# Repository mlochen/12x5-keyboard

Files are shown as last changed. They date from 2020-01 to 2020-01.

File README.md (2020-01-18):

# 12x5 keyboard

CAD file and keymap for an 12x5 keyboard with [qmk firmware](https://qmk.fm/).

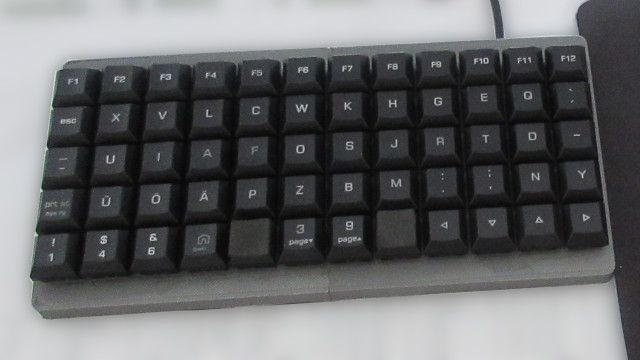
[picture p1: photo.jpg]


This is a hand wired keyboard. It uses the Cherry MX keyswitches and a Teensy 2.0 for the controller board.
The physical layout is a slightly modified version of the [Neo2 layout](https://neo-layout.org/), but the
keyboard can be used with the computer set to the german keyboard layout because the controller converts
the key presses to match the keycodes generated by a standard keyboard.
That makes it possible to use a Neo2 layout on computers that do not support it.

## How to build the firmware
* download the qmk firmware
* copy the "12x5" folder in the keyboards folder
* follow the instructions [here](https://docs.qmk.fm/#/newbs_building_firmware?id=build-your-firmware)

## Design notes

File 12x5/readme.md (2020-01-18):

# 12x5

12x5

A short description of the keyboard/project

Keyboard Maintainer: [Marco Lochen](https://github.com/mlochen)  
Hardware Supported: The PCBs, controllers supported  
Hardware Availability: links to where you can find this hardware

Make example for this keyboard (after setting up your build environment):

    make 12x5:default

See the [build environment setup](https://docs.qmk.fm/#/getting_started_build_tools) and the [make instructions](https://docs.qmk.fm/#/getting_started_make_guide) for more information. Brand new to QMK? Start with our [Complete Newbs Guide](https://docs.qmk.fm/#/newbs).

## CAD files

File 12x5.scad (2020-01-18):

/*
 * Copyright (C) 2019 Marco Lochen
 *
 * This work is licensed under the Creative Commons Attribution 4.0
 * International License. To view a copy of this license, visit
 * http://creativecommons.org/licenses/by/4.0/ or send a letter to Creative
 * Commons, PO Box 1866, Mountain View, CA 94042, USA.
 */

kbx = 228;          // size in x direction
kby = 95;           // size in y direction
bx = 1.8;           // border in x direction
by = 10;            // border in y direction
bh = 9;             // border height
a = 6;              // tilt angle

module base_plate()
{
    difference()
    {
        cube([kbx + 2 * bx, (kby + 2 * by) / cos(a), 1.5]);
        for (x = [0:11])
        {
            for (y = [0:4])
            {
                translate([x * 19 + 9.5 + bx, y * 19 + 9.5 + by, 0]) cube([14, 14, 10], center = true);
            }
        }
    }
}

module bracing()
{
    for (x = [1:11])
    {
        translate([x * 19 + bx - 0.4, -50, 0]) cube([0.8, (kby + 2 * by) / cos(a) + 100, 4]);
    }
    for (y = [1:4])
    {
        translate([-50, y * 19 + by - 0.4, 0]) cube([kbx + 2 * bx + 100, 0.8, 4]);
    }
}

module key_plate()
{
    intersection()
    {
        union()
        {
            base_plate();
            bracing();
        }
        rotate([a, 0, 0]) translate([bx / 2, by / 2, -50]) cube([kbx + bx, kby + by, 100]);
    }
}

module base_border()
{
    difference()
    {
        hull()
        {
            translate([4, 4, 0]) cylinder(h = 100, r = 4, $fn = 16);
            translate([4, kby + 2 * by - 4, 0]) cylinder(h = 100, r = 4, $fn = 16);
            translate([kbx + 2 * bx - 4, 4, 0]) cylinder(h = 100, r = 4, $fn = 16);
            translate([kbx + 2 * bx - 4, kby + 2 * by - 4, 0]) cylinder(h = 100, r = 4, $fn = 16);
        }
        translate([bx, by, -1]) cube([kbx, kby, 102]);
    }
}

module border()
{
    module bolt_cutout(h = 12)
    {
        cylinder(h = kby, r = 1.7, $fn = 16);
        translate([0, 0, -1.5]) cylinder(h = 4, r1 = 4, r2 = 0, $fn = 16);
        translate([0, 2, 1.4 + 3]) cube([5.8, 12, 2.8], center = true);
    }
    
    module wire_cut()
    {
        wire_d = 4.6;
        translate([0, wire_d / 2]) circle(r = wire_d / 2, $fn = 16);
        square([wire_d, wire_d], center = true);
    }
    
    module wire_cutout()
    {
        rotate([90, 0, 0]) linear_extrude(10) wire_cut();
        translate([10, 0, 0]) rotate([0, 0, 45]) rotate_extrude(angle = 135, $fn = 32)
            translate([10, 0]) wire_cut();
        translate([20 / sqrt(2) + 10, 20 / sqrt(2), 0]) rotate([0, 0, 225])
            rotate_extrude(angle = 135, $fn = 32) translate([10, 0]) wire_cut();
    }
        
    difference()
    {
        union()
        {
            base_border();
            translate([50, kby + 2 * by, 0]) difference()
            {
                cylinder(h = 16, r1 = 15, r2 = 10, $fn = 32);
                translate([0, 45, 0]) cube([100, 100, 100], center = true);
            }
        }
        translate([bx + 9.5, by / 2, 0]) bolt_cutout(8);
        translate([bx + 9.5, by + kby + by / 2, 0]) rotate([0, 0, 180]) bolt_cutout();
        translate([bx + kbx / 2 - 9.5, by / 2, 0]) bolt_cutout(8);
        translate([bx + kbx / 2 - 9.5, by + kby + by / 2, 0]) rotate([0, 0, 180]) bolt_cutout();
        translate([bx + kbx / 2 + 9.5, by / 2, 0]) bolt_cutout(8);
        translate([bx + kbx / 2 + 9.5, by + kby + by / 2, 0]) rotate([0, 0, 180]) bolt_cutout();
        translate([bx + kbx - 9.5, by / 2, 0]) bolt_cutout(8);
        translate([bx + kbx - 9.5, by + kby + by / 2, 0]) rotate([0, 0, 180]) bolt_cutout();
        
        translate([40, kby + 2 * by, 0]) mirror([0, 1, 0]) wire_cutout();
        
        translate([24, 2, -1]) cube([30, 6, 6]);
        translate([kbx + 2 * bx - 24 - 30, 2, -1]) cube([30, 6, 6]);
    }
}

module complete()
{
    key_plate();
    
    intersection()
    {
        rotate([a, 0, 0]) translate([0, 0, bh]) mirror([0, 0, 1]) border();
        translate([0, 0, 500]) cube([1000, 1000, 1000], center = true);
    }
}

module half1()
{        
    intersection()
    {
        complete();
        translate([-500 + kbx / 2 + bx, 0, 0]) cube([1000, 1000, 1000], center = true);
    }
}

module half2()
{        
    intersection()
    {
        complete();
        translate([500 + kbx / 2 + bx, 0, 0]) cube([1000, 1000, 1000], center = true);
    }
}

complete();
// for smaller print beds the keyboard can be printed in two halfes and then glued together
//half1();
//half2();

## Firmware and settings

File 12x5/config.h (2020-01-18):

/*
Copyright 2019 Marco Lochen

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
You should have received a copy of the GNU General Public License
along with this program.  If not, see <http://www.gnu.org/licenses/>.
*/

#pragma once

#include "config_common.h"

/* USB Device descriptor parameter */
#define VENDOR_ID 0xFEED
#define PRODUCT_ID 0x0000
#define DEVICE_VER 0x0001
#define MANUFACTURER Marco Lochen
#define PRODUCT 12x5
#define DESCRIPTION A custom keyboard

/* key matrix size */
#define MATRIX_ROWS 5
#define MATRIX_COLS 12

/*
 * Keyboard Matrix Assignments
 *
 * Change this to how you wired your keyboard
 * COLS: AVR pins used for columns, left to right
 * ROWS: AVR pins used for rows, top to bottom
 * DIODE_DIRECTION: COL2ROW = COL = Anode (+), ROW = Cathode (-, marked on diode)
 *                  ROW2COL = ROW = Anode (+), COL = Cathode (-, marked on diode)
 *
 */
#define MATRIX_ROW_PINS \
    { D0, D1, D2, D3, C6 }
#define MATRIX_COL_PINS \
    { D4, D6, D7, B4, B5, B6, F7, F6, F5, F4, F1, F0 }
#define UNUSED_PINS

/* COL2ROW, ROW2COL*/
#define DIODE_DIRECTION COL2ROW

/*
 * Split Keyboard specific options, make sure you have 'SPLIT_KEYBOARD = yes' in your rules.mk, and define SOFT_SERIAL_PIN.
 */
#define SOFT_SERIAL_PIN D0  // or D1, D2, D3, E6

// #define BACKLIGHT_PIN B7
// #define BACKLIGHT_BREATHING
// #define BACKLIGHT_LEVELS 3

// #define RGB_DI_PIN E2
// #ifdef RGB_DI_PIN
//   #define RGBLED_NUM 16
//   #define RGBLIGHT_HUE_STEP 8
//   #define RGBLIGHT_SAT_STEP 8
//   #define RGBLIGHT_VAL_STEP 8
//   #define RGBLIGHT_LIMIT_VAL 255 /* The maximum brightness level */
//   #define RGBLIGHT_SLEEP  /* If defined, the RGB lighting will be switched off when the host goes to sleep */
// /*== all animations enable ==*/
//   #define RGBLIGHT_ANIMATIONS
// /*== or choose animations ==*/
//   #define RGBLIGHT_EFFECT_BREATHING
//   #define RGBLIGHT_EFFECT_RAINBOW_MOOD
//   #define RGBLIGHT_EFFECT_RAINBOW_SWIRL
//   #define RGBLIGHT_EFFECT_SNAKE
//   #define RGBLIGHT_EFFECT_KNIGHT
//   #define RGBLIGHT_EFFECT_CHRISTMAS
//   #define RGBLIGHT_EFFECT_STATIC_GRADIENT
//   #define RGBLIGHT_EFFECT_RGB_TEST
//   #define RGBLIGHT_EFFECT_ALTERNATING
// /*== customize breathing effect ==*/
//   /*==== (DEFAULT) use fixed table instead of exp() and sin() ====*/
//   #define RGBLIGHT_BREATHE_TABLE_SIZE 256      // 256(default) or 128 or 64
//   /*==== use exp() and sin() ====*/
//   #define RGBLIGHT_EFFECT_BREATHE_CENTER 1.85  // 1 to 2.7
//   #define RGBLIGHT_EFFECT_BREATHE_MAX    255   // 0 to 255
// #endif

/* Debounce reduces chatter (unintended double-presses) - set 0 if debouncing is not needed */
#define DEBOUNCE 5

/* define if matrix has ghost (lacks anti-ghosting diodes) */
//#define MATRIX_HAS_GHOST

/* Mechanical locking support. Use KC_LCAP, KC_LNUM or KC_LSCR instead in keymap */
#define LOCKING_SUPPORT_ENABLE
/* Locking resynchronize hack */
#define LOCKING_RESYNC_ENABLE

/* If defined, GRAVE_ESC will always act as ESC when CTRL is held.
 * This is userful for the Windows task manager shortcut (ctrl+shift+esc).
 */
// #define GRAVE_ESC_CTRL_OVERRIDE

/*
 * Force NKRO
 *
 * Force NKRO (nKey Rollover) to be enabled by default, regardless of the saved
 * state in the bootmagic EEPROM settings. (Note that NKRO must be enabled in the
 * makefile for this to work.)
 *
 * If forced on, NKRO can be disabled via magic key (default = LShift+RShift+N)
 * until the next keyboard reset.
 *
 * NKRO may prevent your keystrokes from being detected in the BIOS, but it is
 * fully operational during normal computer usage.
 *
 * For a less heavy-handed approach, enable NKRO via magic key (LShift+RShift+N)
 * or via bootmagic (hold SPACE+N while plugging in the keyboard). Once set by
 * bootmagic, NKRO mode will always be enabled until it is toggled again during a
 * power-up.
 *
 */
//#define FORCE_NKRO

/*
 * Magic Key Options
 *
 * Magic keys are hotkey commands that allow control over firmware functions of
 * the keyboard. They are best used in combination with the HID Listen program,
 * found here: https://www.pjrc.com/teensy/hid_listen.html
 *
 * The options below allow the magic key functionality to be changed. This is
 * useful if your keyboard/keypad is missing keys and you want magic key support.
 *
 */

/* key combination for magic key command */
/* defined by default; to change, uncomment and set to the combination you want */
// #define IS_COMMAND() (get_mods() == MOD_MASK_SHIFT)

/* control how magic key switches layers */
//#define MAGIC_KEY_SWITCH_LAYER_WITH_FKEYS  true
//#define MAGIC_KEY_SWITCH_LAYER_WITH_NKEYS  true
//#define MAGIC_KEY_SWITCH_LAYER_WITH_CUSTOM false
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

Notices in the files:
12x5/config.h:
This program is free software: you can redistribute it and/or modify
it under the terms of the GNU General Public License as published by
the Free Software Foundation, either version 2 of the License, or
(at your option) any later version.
